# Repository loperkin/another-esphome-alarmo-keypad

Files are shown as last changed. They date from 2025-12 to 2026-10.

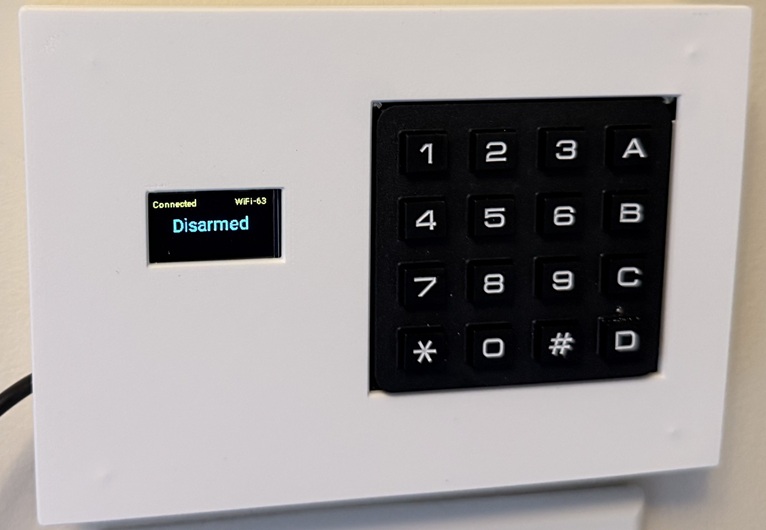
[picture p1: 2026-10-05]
IMG_5698.jpg

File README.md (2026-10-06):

# Another ESPHome Alarmo Keypad

A dedicated, local Wi-Fi alarm keypad built with **ESPHome** for **Home Assistant and Alarmo**.

This project provides a physical keypad for entering a PIN, arming or disarming Alarmo, and displaying the current alarm status without relying on a tablet or touchscreen.

<p align="center">
  Completed ESPHome Alarmo Keypad
</p>

## Why I Built It

I already had an Android tablet that could control Alarmo, but I wanted a more reliable, dedicated way to disarm the house.

A tablet is great when everything is working properly, but tablets, apps, Wi-Fi connections, and dashboards can occasionally flake out. I wanted something simpler that could stay on the wall and have one primary job:

**Enter a PIN and control the alarm.**

I tend to follow the **KISS principle — Keep It Simple, Stupid.**

I didn't need fingerprint readers, RFID tags, cameras, or anything particularly fancy. I wanted a physical keypad, a small display, audible feedback, and a dedicated ESP32 controller that could communicate directly with Home Assistant through ESPHome.

The result is **Another ESPHome Alarmo Keypad**.

## Features

- Physical 4×4 PIN keypad
- Alarmo arm and disarm control
- SSD1306 OLED status display
- Audible buzzer feedback
- ESP32-C3 based
- ESPHome firmware
- Native Home Assistant integration
- Local network operation
- Custom PCB
- Custom 3D-printable wall enclosure
- Configurable Home Assistant automations

## Hardware

### Main Components

- **ESP32-C3 Super Mini** → [Amazon](https://amzn.to/4htXbUB)  
  Larger pack → [Amazon](https://amzn.to/3T9Ncfi)

- **4×4 Matrix Keypad** → [Amazon](https://amzn.to/4ACFlri)

- **SSD1306 128×64 OLED Display** → [Amazon – Yellow & Blue](https://amzn.to/4z5Livp)

- **Buzzer**  
  Active → [Amazon](https://amzn.to/4xStWB8)  
  Passive version used with the PCB → [Amazon](https://amzn.to/3TAuAVQ)

### A Note About the Keypad

The Tegg 4×4 keypad linked above works, but the solder pads can be somewhat fragile if you're not careful while soldering.

This was one of the reasons I eventually designed the custom PCB. The PCB provides a much cleaner and more secure way to connect the keypad and eliminates much of the point-to-point wiring used in the original prototype.

Membrane-style 4×4 keypads should also work if you prefer that style.

### OLED Display

The project uses an **SSD1306 128×64 OLED**.

You don't have to use the exact display linked above. Compatible SSD1306 displays are available in several colors, including white, blue, and yellow/blue combinations.

> **Affiliate Disclosure:** Some of the Amazon links above are affiliate links. I may receive a small commission if you purchase through them at no additional cost to you. These are components and tools that I personally purchased or used while developing this project.

## Optional Supplies

If you're building the original wired version or experimenting with the project, you may also want:

- [Breadboard](https://amzn.to/3VeKENz)
- [Wire](https://amzn.to/4ACFvPq)
- [Jumper Wire Kit](https://amzn.to/3VkdOea)
- [Project Box / Wood Craft Boxes](https://amzn.to/4dfnnBf)
- [Connectors](https://amzn.to/4AGSwr6)
- [USB-C Cables](https://amzn.to/4xXHJGL)
- [USB Power Adapters](https://amzn.to/3TgWXbA)

## Tools

A few basic electronics tools will make the build much easier:

- [Soldering Station](https://amzn.to/4hwRKEj)
- [Solder Flux](https://amzn.to/4hAHv27)
- [Wire Strippers](https://amzn.to/47r0Y0f)

## Wiring

The project can still be assembled without the custom PCB using the original wiring configuration.

<p align="center">
  ESPHome Alarmo Keypad Wiring Diagram
</p>

If you're building a new keypad, I recommend using the custom PCB farther down this page. It significantly reduces the amount of wiring required.

## ESPHome Firmware

The ESPHome configuration for the keypad is located in the **Firmware** folder.

Take some time to read through the configuration before using it. You'll need to copy or modify the appropriate components for your own ESPHome device and Home Assistant installation.

### Programming the ESP32-C3 Super Mini

Some new ESP32-C3 Super Mini boards may repeatedly enter a sleep/reset cycle and can be difficult to flash initially.

If the board won't enter programming mode:

1. Press and hold the **BOOT** button.
2. While continuing to hold BOOT, press and release **RESET**.
3. Release the **BOOT** button.
4. Try flashing the ESP32-C3 again over USB.

Once the initial firmware has been installed, ESPHome can normally handle subsequent updates.

## Home Assistant & Alarmo

Check out the **Automation Examples** included with the project.

The **key entered** automation is particularly important because it passes the PIN entered on the physical keypad to Alarmo.

My example automations have the device and entity IDs removed, so you'll need to select your own devices and entities in Home Assistant.

Using the Home Assistant automation GUI is probably the easiest way to configure those values.

The entered keypad code is available through:

`trigger.event.data.code`

That value can then be passed to Alarmo as part of your arm/disarm automation.

## Keypad Controls

The default configuration uses several of the keypad's function keys:

| Key | Function |
| --- | --- |
| `*` | Delete the last PIN digit entered |
| `C` | Clear the currently entered PIN |
| `A` | Press and hold to arm the alarm when using the example automation |
| `B` | Press and hold to arm Alarmo in **Night Mode** |
| `D` | Submit the entered PIN and disarm Alarmo |

Because the keypad events are exposed through ESPHome and Home Assistant, these controls can be modified to fit your own alarm setup.

## Original Prototype

The first version of this project was built using point-to-point wiring and installed inside a simple project box.

It wasn't particularly elegant, but it worked — and it proved the concept.

<p align="center">
  Original Alarmo Keypad Prototype
  Original Alarmo Keypad Electronics
</p>

### Original Prototype Demo

https://github.com/user-attachments/assets/e2140639-2b51-4e83-94c9-4a3a91e51b54

The prototype worked well enough that I decided it was worth turning into something cleaner and easier to reproduce.

---

# Updated PCB & 3D Printed Case

The original keypad worked, but there was quite a bit of hand wiring inside the project box.

It was time to make it a little **less janky**.

So I designed a custom PCB and matching 3D-printable enclosure specifically for the Alarmo keypad.

## Custom PCB

The custom PCB brings the **ESP32-C3 Super Mini, SSD1306 OLED display, 4×4 keypad, and buzzer** together into a much cleaner package.

It reduces the amount of point-to-point wiring required and makes the finished keypad easier to assemble, troubleshoot, and service.

<p align="center">
  Alarmo Keypad PCB Front
  Alarmo Keypad PCB Back
</p>

The PCB files are available in the **PCB** folder of this repository.

The PCB design is also available on [OSHWHub / OSHWLab](https://oshwlab.com/rockdown/another-esphome-alarmo-keypad).

You can still build the keypad using the original wiring diagram, but the PCB is the recommended approach for a new build.

## 3D Printed Enclosure

I also designed a custom enclosure for the complete keypad assembly.

The goal was to create something that could be mounted on the wall and look more like a finished alarm keypad rather than a collection of development boards and wires stuffed into a project box.

<p align="center">
  Alarmo Keypad 3D Printed Case Front
  Alarmo Keypad 3D Printed Case Back
</p>

The printable files are available in the **3D Print** folder of this repository.

### Print Settings

Recommended starting settings:

- **Material:** PLA or PETG
- **Layer Height:** 0.20 mm
- **Supports:** TBD
- **Infill:** TBD
- **Wall Loops:** TBD

I'll update the recommended settings as the enclosure continues to be refined and tested.

## Finished Keypad

Combining the custom PCB with the printed enclosure turns the original prototype into a much cleaner and more reproducible project.

<p align="center">
  Completed ESPHome Alarmo Keypad
</p>

It's still fundamentally the same simple idea I started with:

**A dedicated physical keypad that does its job without trying to be everything else.**

---

## Project Status

This project is actively being improved. Firmware changes, PCB revisions, enclosure updates, and additional Home Assistant automation examples may be added as I continue using and testing the keypad.

If you build one, modify the design, or find a better way to do something, feel free to share your version.

## 🛒 Purchase Options

Want to build the Alarmo Keypad without having to fabricate every part yourself? A few ready-made options are available.

### 3D Printed Enclosure

A ready-to-use 3D printed enclosure for the Alarmo Keypad.

**[Purchase the 3D Printed Case](https://py.pl/7ZUzHRGNsK6)**

### Bare PCB

The custom Alarmo Keypad PCB with no components installed. This is a good option if you want to source and solder the electronic components yourself.

**[Purchase the Bare PCB](https://py.pl/1d8C3f)**

### Complete Alarmo Keypad Hardware

The complete hardware package including the 3D printed enclosure, custom PCB, and components soldered to the board.

**[Purchase the Complete Alarmo Keypad](https://py.pl/1fJqHh)**

> **Note:** These purchase options are provided for convenience. This remains an open-source project, and the files and documentation in this repository can be used to build the project yourself.

---

## 📜 License

This project is open source, with licensing based on the type of material:

- **Software, ESPHome configurations, Home Assistant automations and code:** MIT License
- **PCB designs, mechanical designs and functional 3D-printable parts:** CERN-OHL-W-2.0
- **Documentation, photos and Purpose in Practice branding:** Copyright © 2026 Lee Perkins unless otherwise noted

See [LICENSE.md](LICENSE.md) for complete licensing information.

You're welcome to learn from it, build it, modify it, and improve it.

**Learn it. Build it. Put it into practice.**

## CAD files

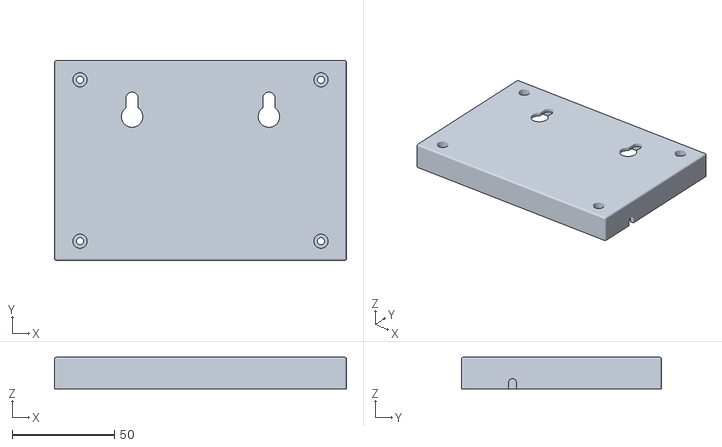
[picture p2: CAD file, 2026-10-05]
3D Print/Keypad back case.stl
143.0 x 98.0 x 15.5

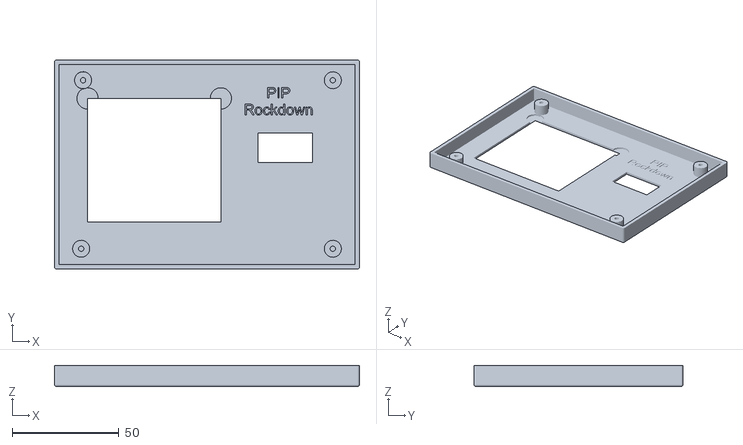
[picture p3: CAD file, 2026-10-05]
3D Print/Keypad Front case.stl
143.0 x 98.0 x 10.0

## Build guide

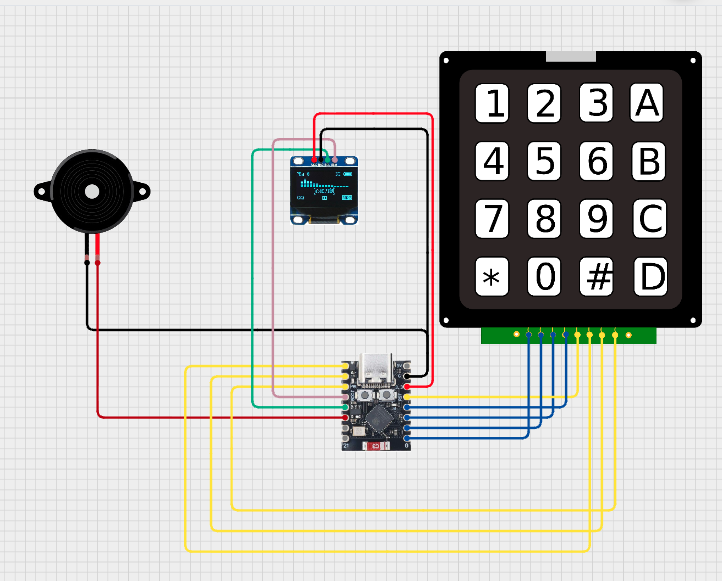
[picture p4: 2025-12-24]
WiringDiagram.png

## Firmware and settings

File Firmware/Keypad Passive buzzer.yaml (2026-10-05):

#I used a esp32-c3 super mini for this. I had some already and I like it because it is compact. There are esp boards with the display built in.  
esp32:
  board: esp32-c3-devkitm-1
  framework:
    type: esp-idf

wifi:
  ssid: !secret wifi_ssid
  password: !secret wifi_password
  # This output power actually lowers the signal strength but apparently slightly lowing it makes it more stable. maybe?
  output_power: 17dB
 
  # some variables to use with the display and key collector
globals:
  - id: pin_string
    type: std::string
    initial_value: ""
  - id: hidden_string
    type: std::string
    initial_value: ""

captive_portal:

# The Web server is helpful with troubleshooting this device. Lets you see what is going on locally at the controller. For more security might want to comment out. 
web_server:
  port: 80
  include_internal: true

sensor:
  - platform: wifi_signal
    name: "Keypad WiFi Signal"
    id: wifi_signal_db
    update_interval: 10s

# Text Sensor is getting the alarmo status and then converting that to look nice. 
text_sensor:
  - platform: homeassistant
    entity_id: alarm_control_panel.alarmo
    name: Alarm State
    id: alarm_status
    
  - platform: template
    name: "Display Status"
    id: display_status
    update_interval: 3000ms
    lambda: |-
      if (id(alarm_status).state == "disarmed") {
        return std::string("Disarmed");
      } else if (id(alarm_status).state == "armed_away") {
        return std::string("Armed Away");
      } else if (id(alarm_status).state == "armed_night") {
        return std::string("Armed Night");
      } else if (id(alarm_status).state == "arming") {
        return std::string("Arming");
      } else if (id(alarm_status).state == "pending") {
        return std::string("Pending");
      } else if (id(alarm_status).state == "triggered") {
        return std::string("Triggered");
      } else {
        return std::string("");
      }
   
# font be sure to load one in your esphome folder "*.ttf" . Direct connection to google fonts is available but it might be best to download and make local.  
font:
  - file: "Roboto-Regular.ttf"
    id: font20
    size: 20

  - file: "Roboto-Regular.ttf"
    id: font10
    size: 10
    
# Display
i2c:
  sda: GPIO8
  scl: GPIO9

display:
  - platform: ssd1306_i2c
    id: oled1
    model: "SSD1306 128x64"
    update_interval: 1000ms
    address: 0x3C
    #change hidden_string to pin_string if you want to visually see the pin
    lambda: |-
      // Top left - Home Assistant / ESPHome API connection
      if (api::global_api_server->is_connected()) {
        it.print(0, 0, id(font10), TextAlign::TOP_LEFT, "Connected");
      } else {
        it.print(0, 0, id(font10), TextAlign::TOP_LEFT, "Sys Unavailable");
      }

      // Top right - WiFi signal
      if (!isnan(id(wifi_signal_db).state)) {
        it.printf(128, 0, id(font10), TextAlign::TOP_RIGHT,
                  "WiFi %.0f", id(wifi_signal_db).state);
      }

      // Alarm status
      it.printf(64, 17, id(font20), TextAlign::TOP_CENTER,
                "%s", id(display_status).state.c_str());

      // PIN entry
      it.printf(64, 42, id(font20), TextAlign::TOP_CENTER,
                "%s", id(hidden_string).c_str());
                
# Keypad Matrix
matrix_keypad:
  id: mykeypad
  rows:
    - pin: GPIO4
    - pin: GPIO5
    - pin: GPIO6
    - pin: GPIO7
  columns:
    - pin: GPIO0
    - pin: GPIO1
    - pin: GPIO2
    - pin: GPIO3
  keys: "123A456B789C*0#D"
  has_diodes: False

# This is to pass the A key to home assistant to make an automation arm alarmo. I do not use codes to arm. 
binary_sensor:
  - platform: matrix_keypad
    keypad_id: mykeypad
    name: "Key A"
    id: keyA
    key: A
  - platform: matrix_keypad
    keypad_id: mykeypad
    name: "Key B"
    id: keyB
    key: B
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

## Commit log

2026-10-05 Create Keypad Passive buzzer.yaml
    [Keypad Passive buzzer.yaml]
2026-10-05 Update Keypad Passive buzzer.yaml
    [Keypad Passive buzzer.yaml]
